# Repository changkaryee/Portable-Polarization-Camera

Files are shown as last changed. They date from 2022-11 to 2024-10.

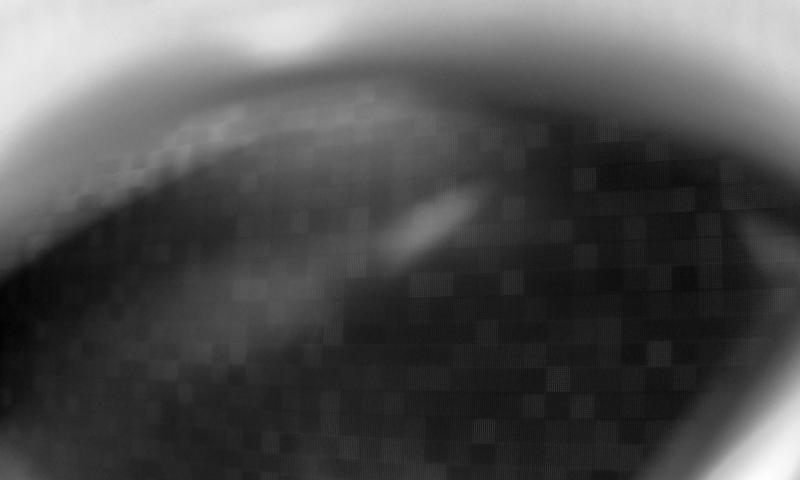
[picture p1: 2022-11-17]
polar cam Files/Examples/Example of Computer Screen/Screen S2.jpg

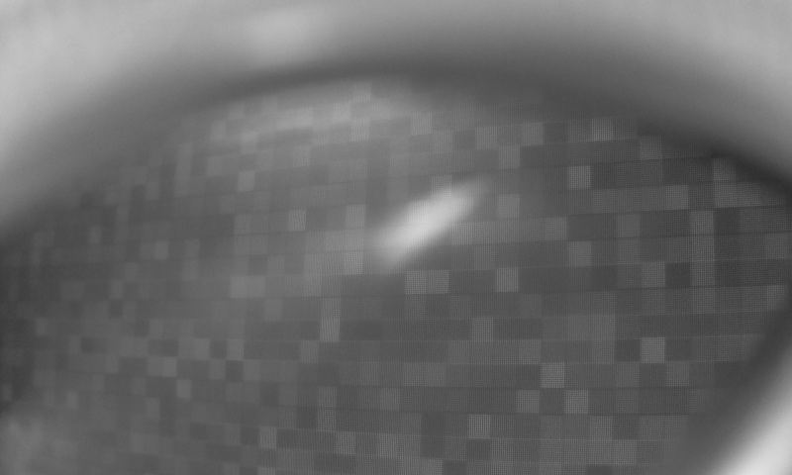
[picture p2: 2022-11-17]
polar cam Files/Pics45/fourtyfive_gray.tif

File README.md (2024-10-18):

# Portable-Polarization-Camera
Introduction:
During the summer of 2022, I began working on a portable polarization camera. Thanks to Dr. Yao’s optical research lab, I gained the knowledge needed to execute this project. My mentor, Jia Wei Zhuo, was an integral part of this process because he taught and introduced me to photonics.

Hypothesis:
By utilizing Stokes parameters, I should be able to create a camera that can see the polarization of different surfaces.

Setup:
3D print all of the pieces in the folder-
Connect piece 1 to piece 2 with superglue-
Attach Raspberry Pie through the hole in piece 1-
Attach the Camera to piece 2 and connect the Camera to the raspberry pie via an Adafruit Flex Cable-
Grab a sheet of polarization film, place the short edge towards your body(this is 0°)-
rotate 45° and cut a sheet out
repeat steps 5 and 6 until you have 4 small pieces of film. Make sure they are organized-
tape the film to the film wheel-
attach a bearing into the film wheel(0.5 in tall, 2 in wide) and the pieces 1+2-

Procedure:
Position the camera and press the button, then wait for 2 minutes.

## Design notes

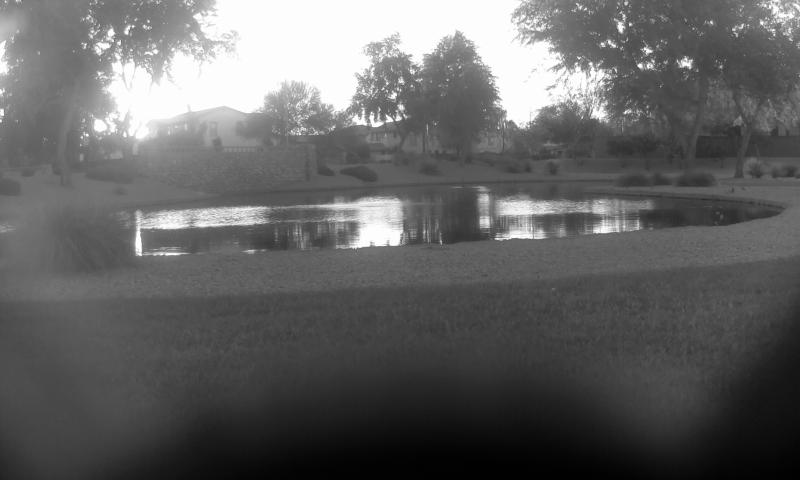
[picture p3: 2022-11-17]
polar cam Files/Examples/Example of Lake/Lake S2.jpg

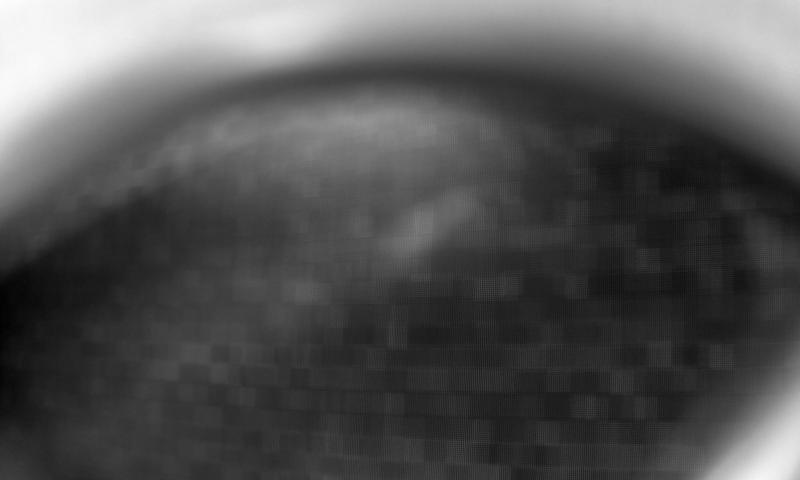
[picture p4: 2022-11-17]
polar cam Files/Examples/Example of Computer Screen/Screen S0.jpg

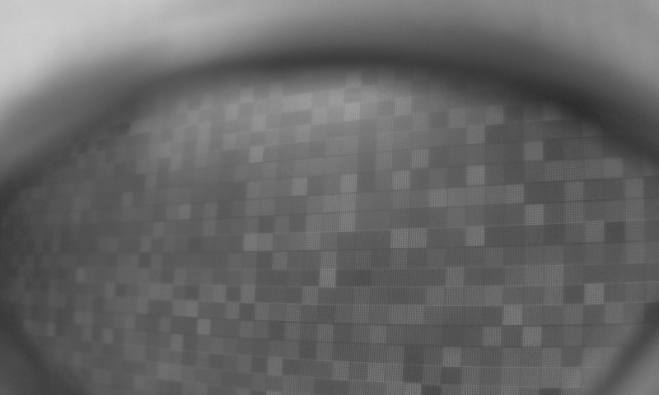
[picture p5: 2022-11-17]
polar cam Files/Pics0/zero_gray.tif

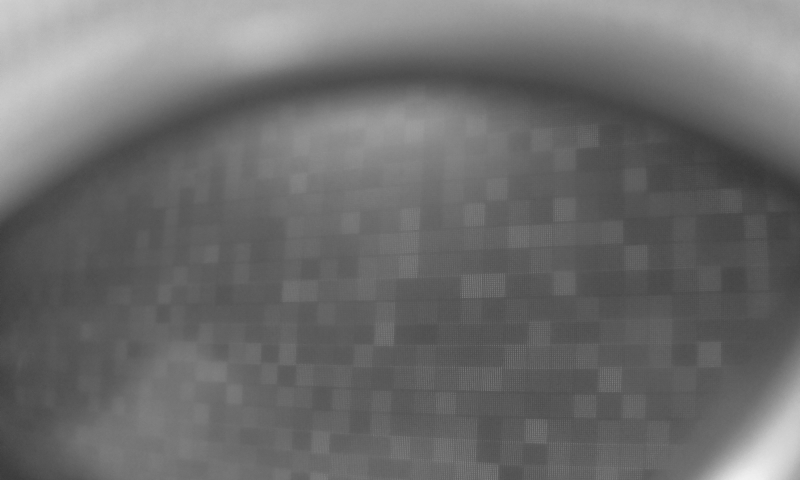
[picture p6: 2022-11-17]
polar cam Files/Pics90/ninety_gray.tif

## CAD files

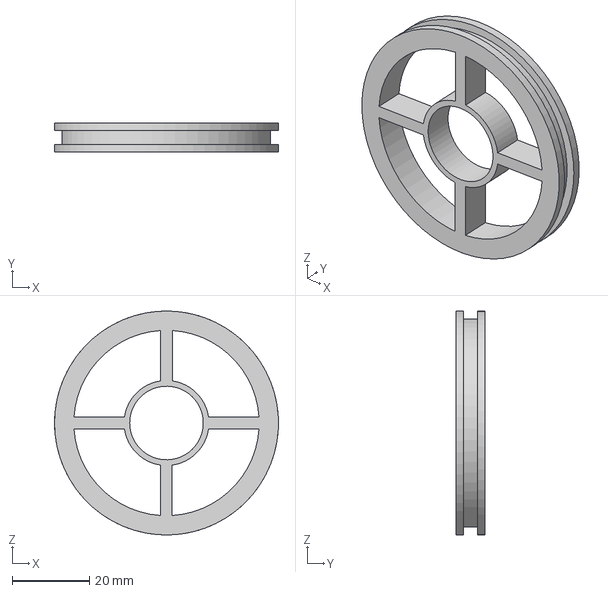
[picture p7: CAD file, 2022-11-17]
Cad Files/Polar Film Wheel.step
58.0 x 7.50 x 58.0 mm

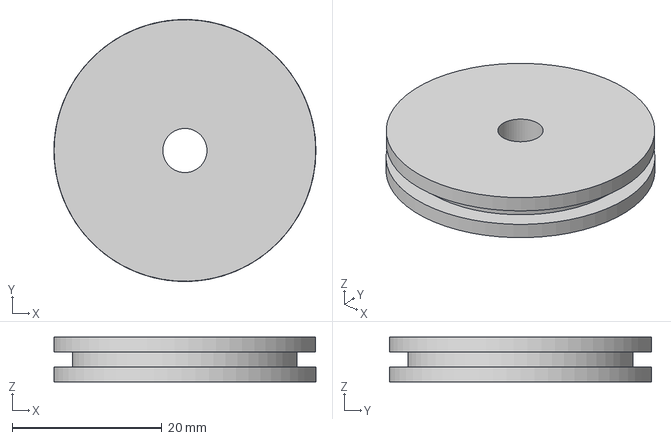
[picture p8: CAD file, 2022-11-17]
Cad Files/Motor Wheel.step
35.0 x 35.0 x 6.00 mm

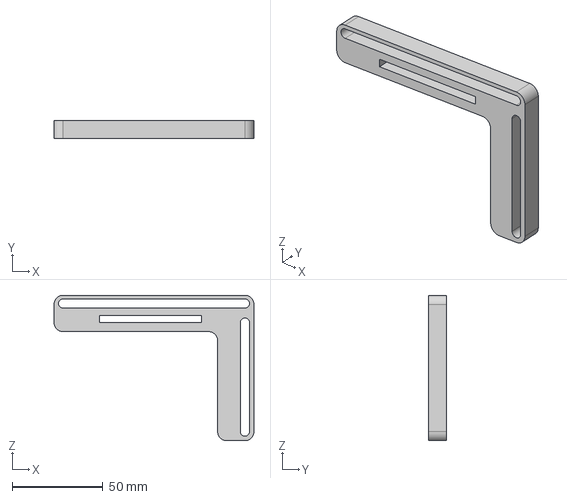
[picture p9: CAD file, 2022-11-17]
Cad Files/Part 1.step
110.0 x 10.0 x 80.0 mm

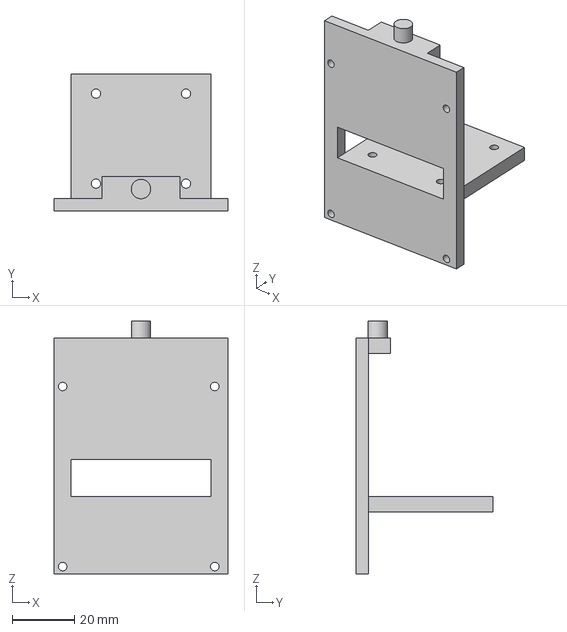
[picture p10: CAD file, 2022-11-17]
Cad Files/Part 2.step
56.0 x 44.0 x 81.5 mm

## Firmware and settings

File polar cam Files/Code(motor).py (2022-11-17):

from picamera import PiCamera
import time
import RPi.GPIO as GPIO

servoPIN = 17
GPIO.setmode(GPIO.BCM)
GPIO.setup(servoPIN, GPIO.OUT)

p = GPIO.PWM(servoPIN, 50) # GPIO 17 for PWM with 50Hz
p.start(0) # Initialization
time.sleep(5)
p.stop

def run():
#0 degrees
    print("taking picture of 0 degrees")
    camera = PiCamera()
    time.sleep(8)

    camera.capture("/home/pi/Desktop/Edmund's project/Pics0/img.jpg")
    camera.close()
    print("done.")
#45 degrees
    p.ChangeDutyCycle(4+(11.25)/18)
    time.sleep(1)
    p.ChangeDutyCycle(0)
    
    print("taking picture of 45 degrees")
    time.sleep(8)

    camera.capture("/home/pi/Desktop/Edmund's project/Pics45/img.jpg")
    camera.close()
    print("done.")
#90 degrees
    p.ChangeDutyCycle(4+(11.25/18))
    time.sleep(1)
    p.ChangeDutyCycle(0)
    
    print("taking picture of 90 degrees")
    time.sleep(8)

    camera.capture("/home/pi/Desktop/Edmund's project/Pics90/img.jpg")
    camera.close()
    print("done.")
#135 degrees
    p.ChangeDutyCycle(4+(11.25/18))
    time.sleep(1)
    p.ChangeDutyCycle(0)
    
    print("taking picture of 135 degrees")
    time.sleep(8)

    camera.capture("/home/pi/Desktop/Edmund's project/Pics135/img.jpg")
    camera.close()
    print("done.")
    return
camera=PiCamera()
camera.start_preview()
time.sleep(10)
print("ready")
camera.stop_preview()
camera.close
run()
p.stop
#for ZERO
camera.close()
I = Image.open('/home/pi/Desktop/Edmunds project/Pics0/zero.jpg')
#image proccessing for zero
I1 =I.convert('L')

#Matrix
I1.save('/home/pi/Desktop/Edmunds project/Pics0/zero_gray.tif')
azero = np.asarray(I1,dtype=np.float32)
#Image.fromarray(azero.astype(np.uint8)).save("/home/pi/Desktop/Edmunds project/Pics0/test0.jpg")

#writing 0 array in matrix text file
with open("/home/pi/Desktop/Edmunds project/Pics0/Matrix 0","w") as tzero:
    for item in azero:
        tzero.write("%s\n" % item)

print("Matrix for 0 done")
#for ninety

I = Image.open("/home/pi/Desktop/Edmunds project/Pics90/ninety.jpg")

#Image proccessing for ninety

I2 = I.convert('L')

#Matrix

I2.save('/home/pi/Desktop/Edmunds project/Pics90/ninety_gray.tif')
aninety = np.asarray(I2,dtype=np.float32)
# Image.fromarray(azero.astype(np.uint8)).save("/home/pi/Desktop/Edmunds project/Pics90/test0.jpg")

#writing 90 array in matrix text file
with open("/home/pi/Desktop/Edmunds project/Pics90/Matrix 90","w") as tninety:
    for item in aninety:
        tninety.write("%s\n" % item)
print("Matrix for 90 done")
#for hundredthirtyfive

I = Image.open("/home/pi/Desktop/Edmunds project/Pics135/hundredthirtyfive.jpg")

#Image proccessing for hudredthirtyfive

I3 = I.convert('L')

#Matrix

I3.save('/home/pi/Desktop/Edmunds project/Pics135/hundredthirtyfive_gray.tif')
ahundredthirtyfive = np.asarray(I3,dtype=np.float32)
# Image.fromarray(azero.astype(np.uint8)).save("/home/pi/Desktop/Edmunds project/Pics90/test0.jpg")

#writing 135 array in matrix text file
with open("/home/pi/Desktop/Edmunds project/Pics135/Matrix 135","w") as thundredthirtyfive:
    for item in ahundredthirtyfive:
        thundredthirtyfive.write("%s\n" % item)

print("Matrix for 135 done")
#for FOURTYFIVE

I = Image.open('/home/pi/Desktop/Edmunds project/Pics45/fourtyfive.jpg')
#image proccessing for zero
I4 =I.convert('L')

#Matrix
I4.save('/home/pi/Desktop/Edmunds project/Pics45/fourtyfive_gray.tif')
afourtyfive = np.asarray(I4,dtype=np.float32)
#Image.fromarray(azero.astype(np.uint8)).save("/home/pi/Desktop/Edmunds project/Pics0/test0.jpg")

#writing 45 array in matrix text file
with open("/home/pi/Desktop/Edmunds project/Pics45/Matrix 45","w") as tfourtyfive:
    for item in afourtyfive:
        tfourtyfive.write("%s\n" % item)
print("Matrix for 45 done")
#Normalize Function
def normalize(I):
    mn = I.min()
    mx = I.max()
    mx = mx-mn
    
    I = ((I-mn)/mx) * 255
    return I.astype(np.uint8)

#Looking for S0
S0 = azero+aninety+ahundredthirtyfive+afourtyfive
S0 = np.divide(S0,2)
Image.fromarray(normalize(S0).astype(np.uint8)).save("/home/pi/Desktop/Edmunds project/S0.jpg")
with open("/home/pi/Desktop/Edmunds project/Matrix S0","w") as Stokes0:
    for item in S0:
        Stokes0.write("%s\n" % item)
print("S0 done")
#Looking for S1
S1 = azero-aninety
Image.fromarray(normalize(S1).astype(np.uint8)).save("/home/pi/Desktop/Edmunds project/S1.jpg")
with open("/home/pi/Desktop/Edmunds project/Matrix S1","w") as Stokes1:
    for item in S1:
        Stokes1.write("%s\n" % item)
print("S1 done")
#Looking for S2:
S2 = afourtyfive+ahundredthirtyfive
Image.fromarray(normalize(S2).astype(np.uint8)).save("/home/pi/Desktop/Edmunds project/S2.jpg")
with open("/home/pi/Desktop/Edmunds project/Matrix S2","w") as Stokes2:
    for item in S2:
        Stokes2.write("%s\n" % item)
print("S2 done")
#Looking for DOLP
DOLP = S1 * S1 + S2 * S2
#Image.fromarray(DOLP.astype(np.uint8)).show()
DOLP = np.sqrt(DOLP)

#Image.fromarray(DOLP.astype(np.uint8)).show()
DOLP = (DOLP)/(S0+1)
#Image.fromarray(DOLP.astype(np.uint8)).show()


Image.fromarray(normalize(DOLP).astype(np.uint8)).save("/home/pi/Desktop/Edmunds project/Dolp.jpg")
with open("/home/pi/Desktop/Edmunds project/Matrix Dolp","w") as D:
    for item in DOLP:
        D.write("%s\n" % item)

print("DOLP done")

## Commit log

2022-11-17 Rename Code.py to Code(with motor).py
2022-11-17 Rename Test Code.py to Code(without motor).py
2022-11-17 Create CAD Files
2022-11-17 Update and rename Code.py to Code(motor).py
2022-11-17 Update and rename Test Code.py to Code(without motor).py
